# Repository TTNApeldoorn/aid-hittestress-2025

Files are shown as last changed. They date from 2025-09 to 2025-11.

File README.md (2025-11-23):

# aid-hittestress-2025

These climate sensors are designed for the LIFE-IP Climate adaption project in Apeldoorn. The sensors measures temperature, humidity and air quality.
The sensors are mounted in lampposts and communicate via LoRAWan with the TTN network.

## Requirements 
- The sensor measures each 2.5 minutes temperatue, humidity and particular matter PM1.0, 2.5 and 10
- The sensor sends the measurements to the TTN network using LoRaWan radio
- The sensor can be mounted on lamppost (case IP65)
- The sensor operates on LiPo battery (for minimal 18 hours) and can be charged by 230V supply 
- The sensor battery is charged at night by the lamppost
- GPS location and battery voltage are reported at regular intervals

## Realization

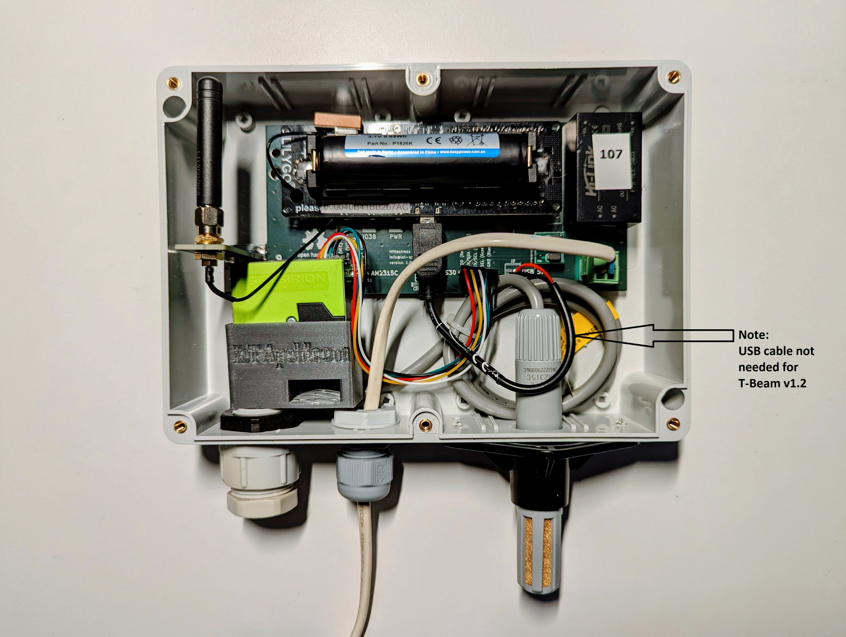
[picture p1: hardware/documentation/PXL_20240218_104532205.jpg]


 Climate Sensor in Kradex housing

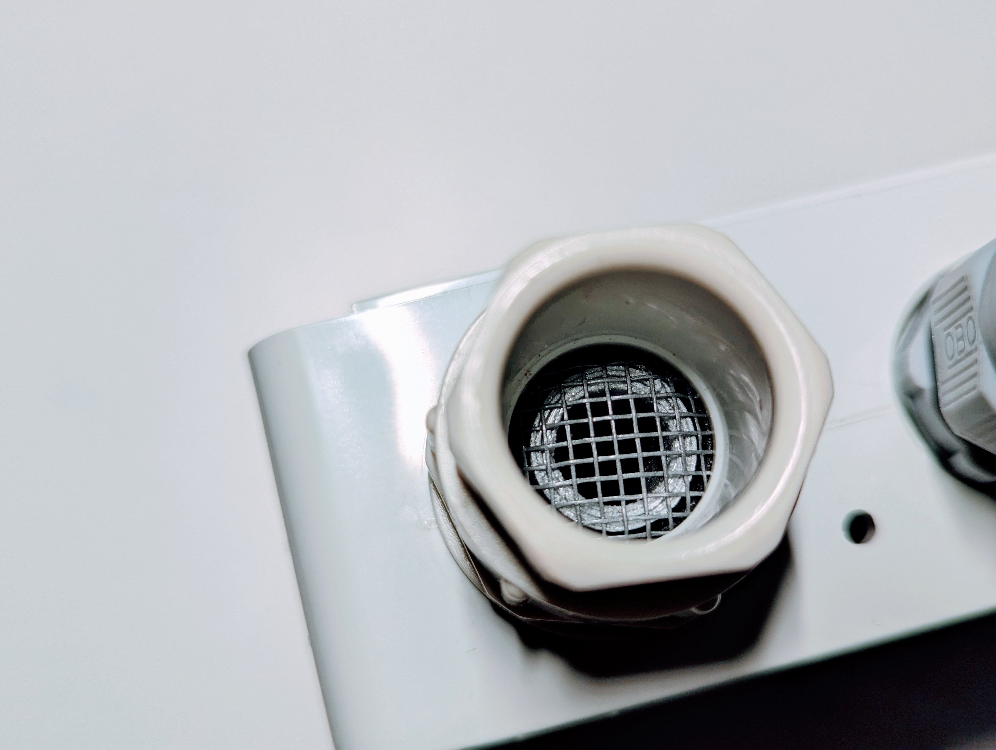
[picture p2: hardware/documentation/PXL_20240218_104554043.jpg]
 

Air inlet particle sensor, with insect sreen

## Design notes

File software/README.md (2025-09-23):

# LIFE-IP Climate sensor 2025
These climate sensors are designed for the LIFE-IP climate adaption project in Apeldoorn.

## Hardware:
- LilyGO TTGO T-Beam V1.2 - LoRa 868MHz - NEO-M8N GPS - ESP32 
- Sensirion SPS30 Particulate matter sensor i2c
- AM2315C Temperature/humidity sensor i2c
- 18650 Li-ion Batterij - 2600mAh
- Hi-Link PCB Supply - 5VDC 1A
- Mini DC-DC 5V Step-up Boost Converter 480mA
- PCB for connecting components
- Kradex housing 176x126x57mm - IP65

Note that there exist several different types of LilyGo T-Beam versions with different power managent modules and LoRa modules. This documentation describes the **LilyGO T-Beam V1.2** with:
- AXP2101 power module
- SX1276 LoRa module
- NEO-M8N GNSS GPS module

More info see https://github.com/Xinyuan-LilyGO/LilyGo-LoRa-Series
## Software 

### Prerequisites:
- Visual Studio with Platform IO
- LMIC-Arduino LoRa library
- mikalhart/TinyGPSPlus GPS library
- sensirion/sensirion-sps particicle matter SPS30 library
- lewisxhe/XPowersLib power control AXP2101
- RobTillaart/AM2315C library for the i2c AM2315C sensor
- espressif32@6.9.0 platform with board lilygo t-beam

The **platformio.ini** takes care for the required settings end libraries. LMIC library is already included in the project sources.

## Instructions
### LoRaWan TTN keys
The file **utilities.h** defines the TTN keys APPEUI and APPKEY.
The unique DEVEUI key is obtained from the T-BEAM board id.

## TTN interface
Two type of messages are sent by the sensor:
- measurement report (each 2.5 minutes), send on TTN port 15
- status report (eachtime after 100 measurement reports), send on TTN port 16

Measurement report contains:
- temperature in C
- Relative Humidity in %
- Particulate Matter 1.0 μg/m3
- Particulate Matter 2.5 μg/m3
- Particulate Matter 10 μg/m3
- Battery voltage in V

Status report contains:
- GPS position lat/lon, hdop, altitude
- Sensor version
- batterij voltage

The binary messages from the Sensor are converted by the TTN Payloaddecoder into Json.  
Example JSON measurement message:

> {"pm10":8.5,"pm1p0":7.22,"pm2p5":8.02,"rh":99.99,"temp":7.82,"vbat":4.037}

Example JSON status message:
> {"latitude":52.224578,"longitude":6.0061902,"alt":0.0,"hdop":1.61,vbat":4.099,"SwVer":3.02 }

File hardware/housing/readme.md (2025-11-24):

# Drillplan

This is the [drillplan](drillPlan.png) for the housing. 
The drill plan shows the bottom plane of a [Kradex Z74 ABS enclosure](../documentation/Z74.pdf).

## Overview of the housing

Overview interals of housing

>This is the previous version using the older version of the Heltec T-Beam that is powered over USB.

SDS030 particle sensor raster inlet

>This shows the raster of the SPS30 particle sensor.

## SPS30 holder

The [SPS30 holder](hittestress2025_SPS_omhulsel_TPU.stl) is a devative work from [pe0ter](https://www.thingiverse.com/pe0ter) his [SPS30 PM sensor adapter](https://www.thingiverse.com/thing:4851976).

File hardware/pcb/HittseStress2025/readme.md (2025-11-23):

# HittseStress2025 PCB Design

This directory contains the KiCad project files for the HittseStress2025 printed circuit board (PCB). This PCB is designed to interface the TTGO T-Beam ESP32 LoRa module with the SPS30 particulate matter sensor and other components for the climate sensor system.

## Contents

- `HittseStress2025.kicad_pcb` - PCB layout file
- `HittseStress2025.kicad_sch` - Schematic file
- `HittseStress2025.kicad_pro` - KiCad project file
- `gerbers/` - Gerber files for PCB manufacturing
- `my-KiCad-library/` - Custom KiCad symbols and footprints
- `HittseStress2025-backups/` - Automatic backup files

## Purpose

The PCB serves as a shield/breakout board that provides:
- Power management connections
- Interface connections for the SPS30 particulate matter sensor
- Proper pin routing for the ESP32-based TTGO T-Beam module
- Support for battery charging and power supply from the lamppost

This board enables the climate sensor to be mounted in lampposts and operate on battery power with charging capability.

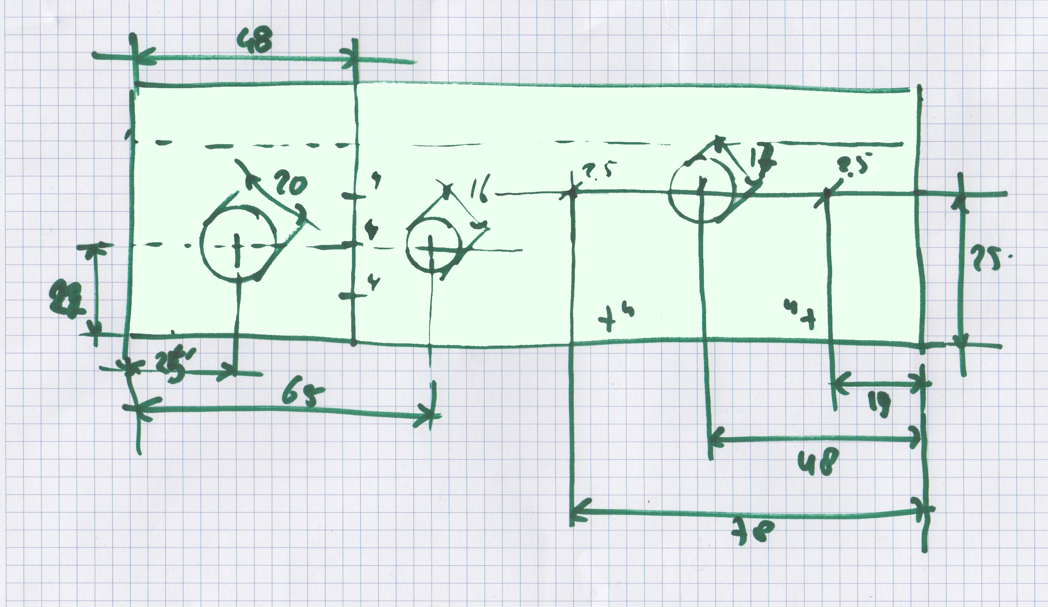
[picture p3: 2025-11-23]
hardware/housing/drillPlan.jpg

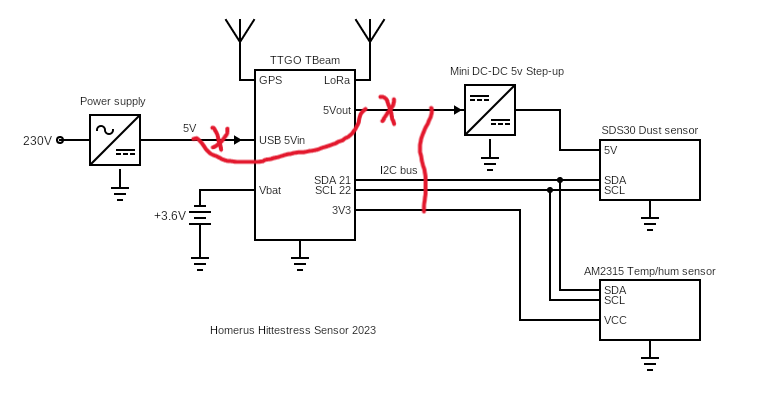
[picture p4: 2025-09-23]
hardware/pcb/workbench/wijziging-schema.png

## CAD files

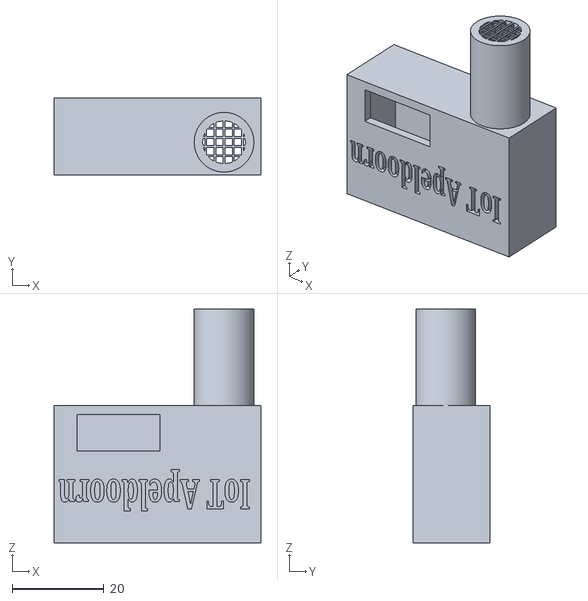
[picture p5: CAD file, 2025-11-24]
hardware/housing/hittestress2025_SPS_omhulsel_TPU.stl
45.0 x 16.7 x 51.0

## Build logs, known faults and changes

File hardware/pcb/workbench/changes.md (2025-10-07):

Er zijn helaas toch nog wat PCB wijzigingen.
De 5V pin van de LilyGO T-Beam V1.2 is nu zowel input als output en is gekoppeld met de USB 5V. Dus de micro-USB stekker kan hiermee vervallen.
Deze 5V pin geeft geen output meer als de sensor op batterij draait, dat was bij de oude versie wel zo.
Dus nu moet de input pin van de step-up (nodig voor de SDS10) aan de 3V3 van de T-Beam aangesloten worden i.p.v. de 5V output.
Ik heb dit aangepast met 2 draadjes en een spoortje doorkrassen, zie foto.

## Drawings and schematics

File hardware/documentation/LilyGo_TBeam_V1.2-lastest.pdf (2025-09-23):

D

5 | 4 | 3 | 2 | 1

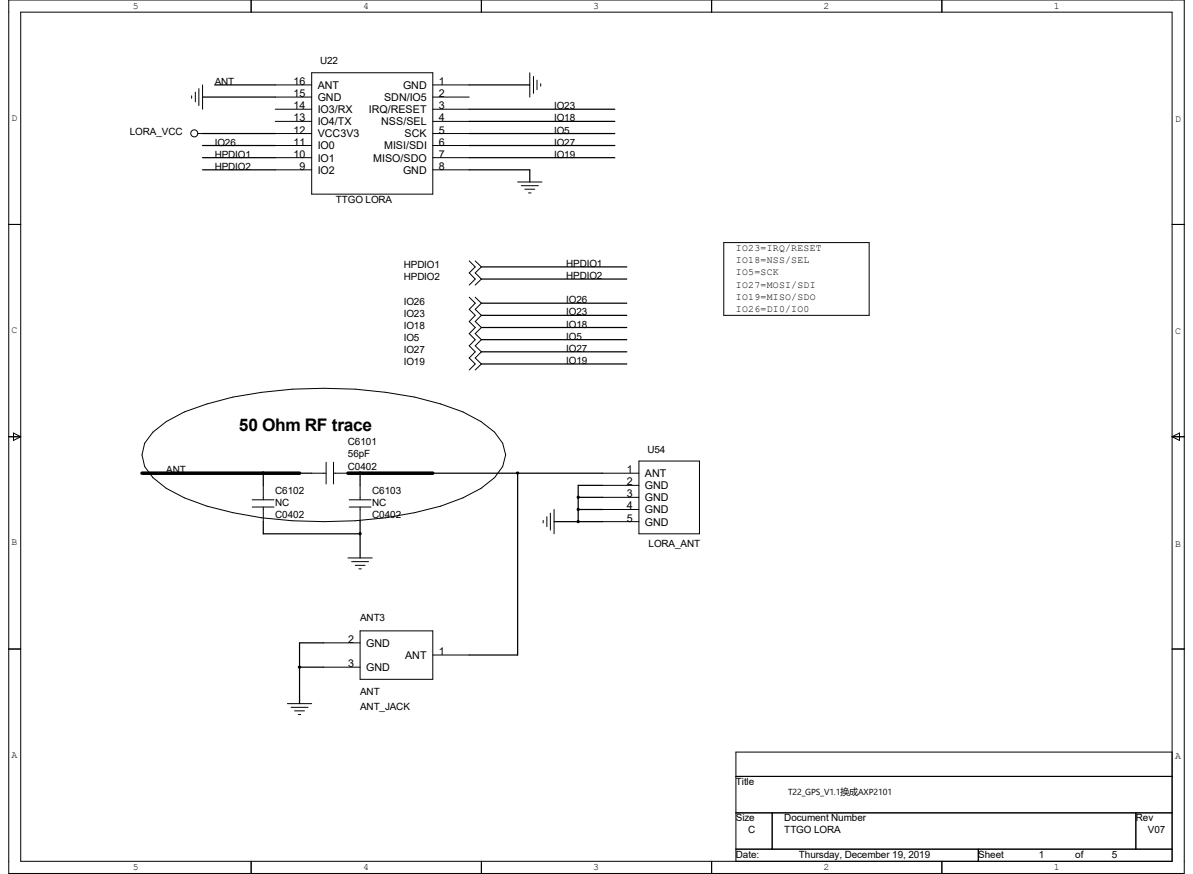
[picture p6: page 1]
T22_GPS_V1.1换成AXP2101; Title; IO23=IRQ/RESET IO18=NSS/SEL IO5=SCK IO27=MOSI/SDI IO19=MISO/SDO IO26=DI0/IO0; 1 ANT 2 GND 3 GND 4 GND 5 GND; LORA_ANT; 1 ANT; 2 GND; 3 GND; ANT3; ANT_JACK; ANT; 16 ANT; MISO/SDO; MISI/SDI; 5 SCK; 4 NSS/SEL; 12 VCC3V3; GND; 3 IRQ/RESET; 2 SDN/IO5; 15 GND; TTGO LORA; LORA_VCC; HPDIO1 HPDIO2; HPDIO2; HPDIO1

50 Ohm RF trace

Size C | Document Number TTGO LORA | Rev V07

Date: Thursday, December 19, 2019 | Sheet 1 of 5

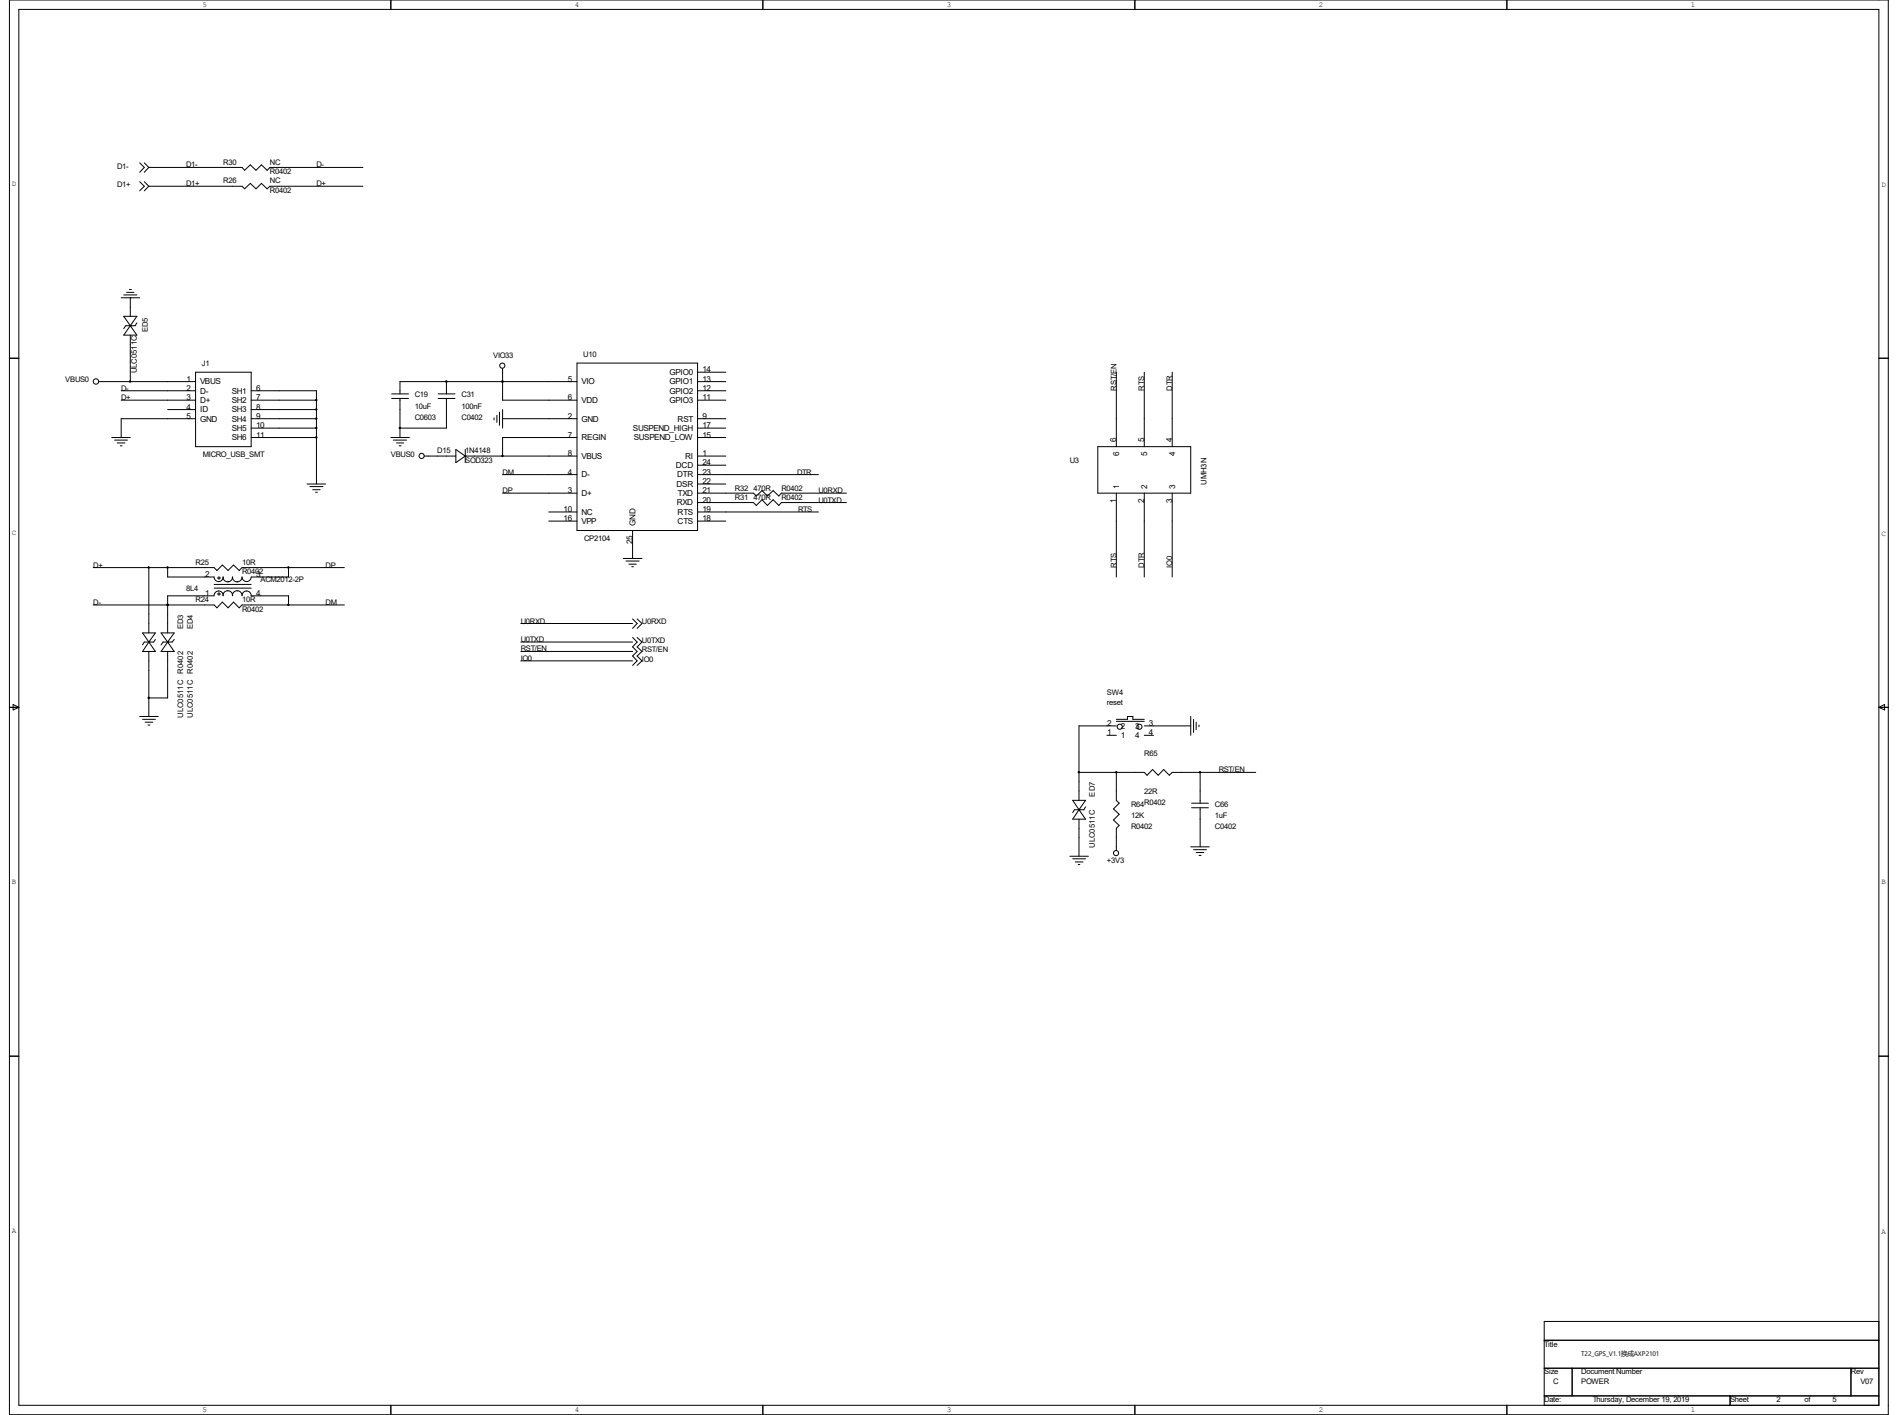
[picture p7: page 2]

RST/EN

D
D

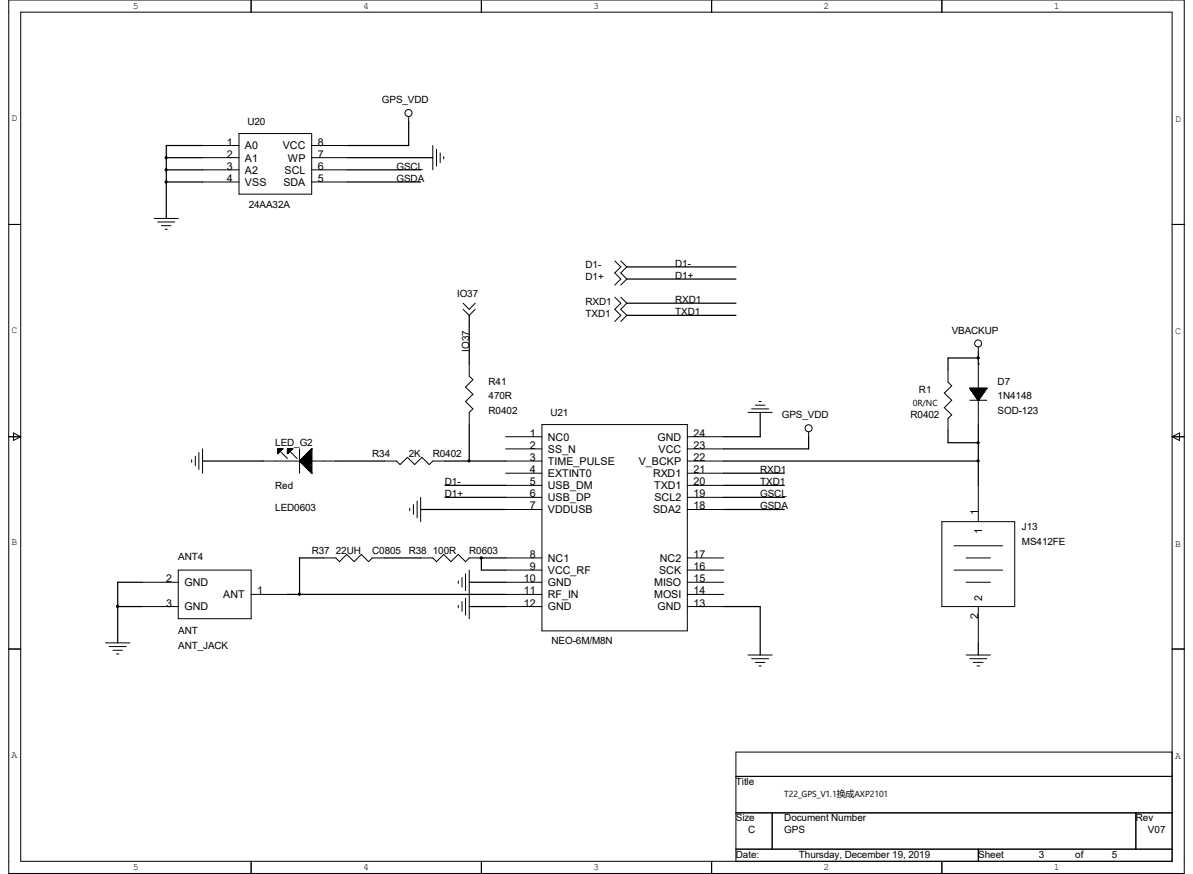
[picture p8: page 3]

C | GPS | V07

Date: | Sheet 3 of 5

# ESP32 Module:with 1.8V Flash & SRAM

The operating voltage for signals marked in blue is 1.8V.

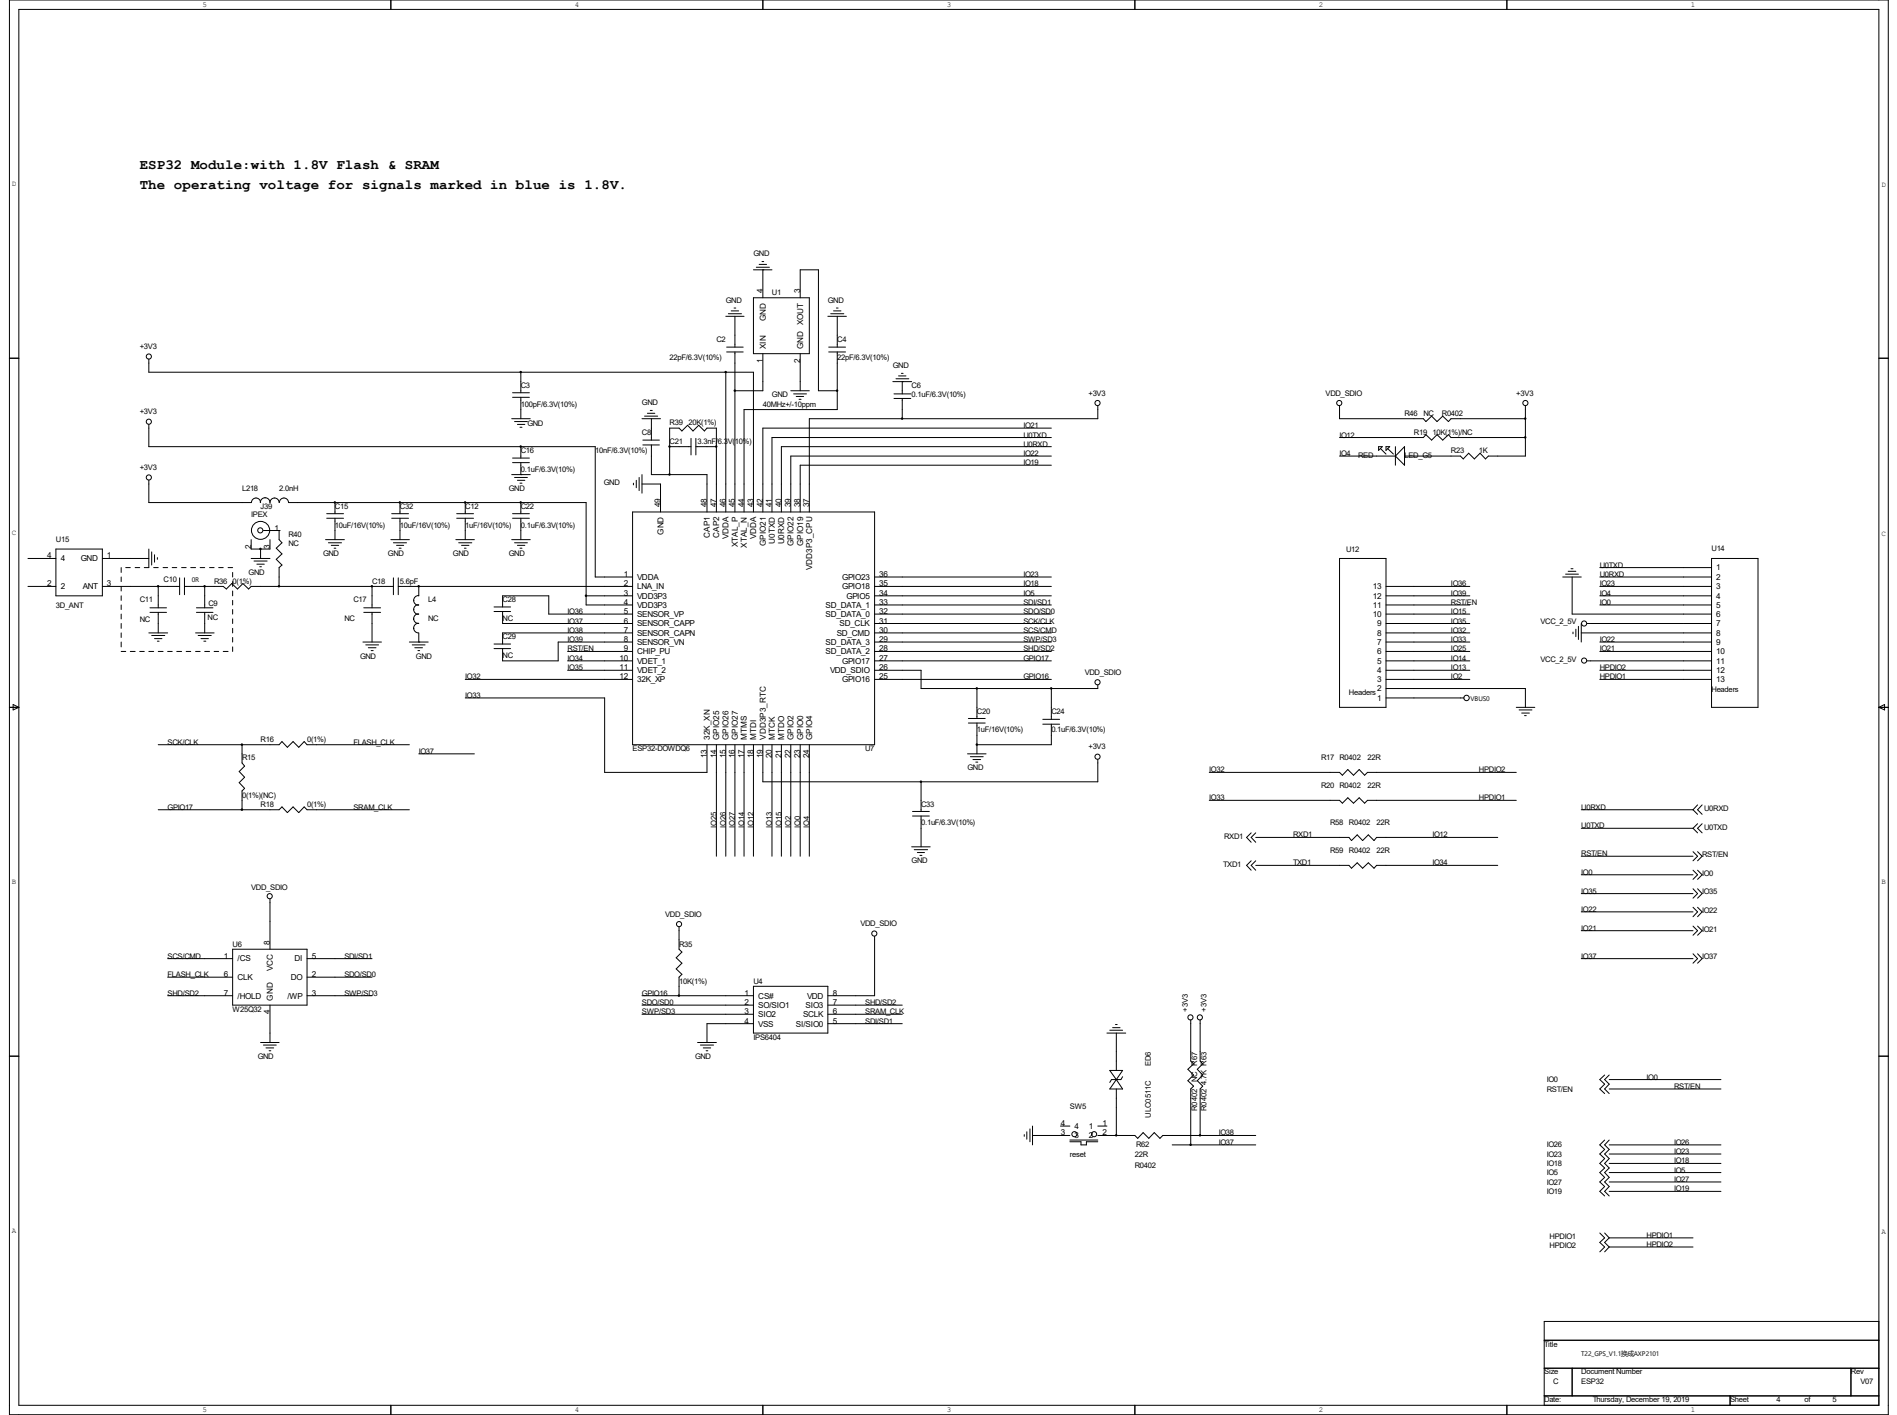
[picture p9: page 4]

## above 30 miles

## above 50 miles

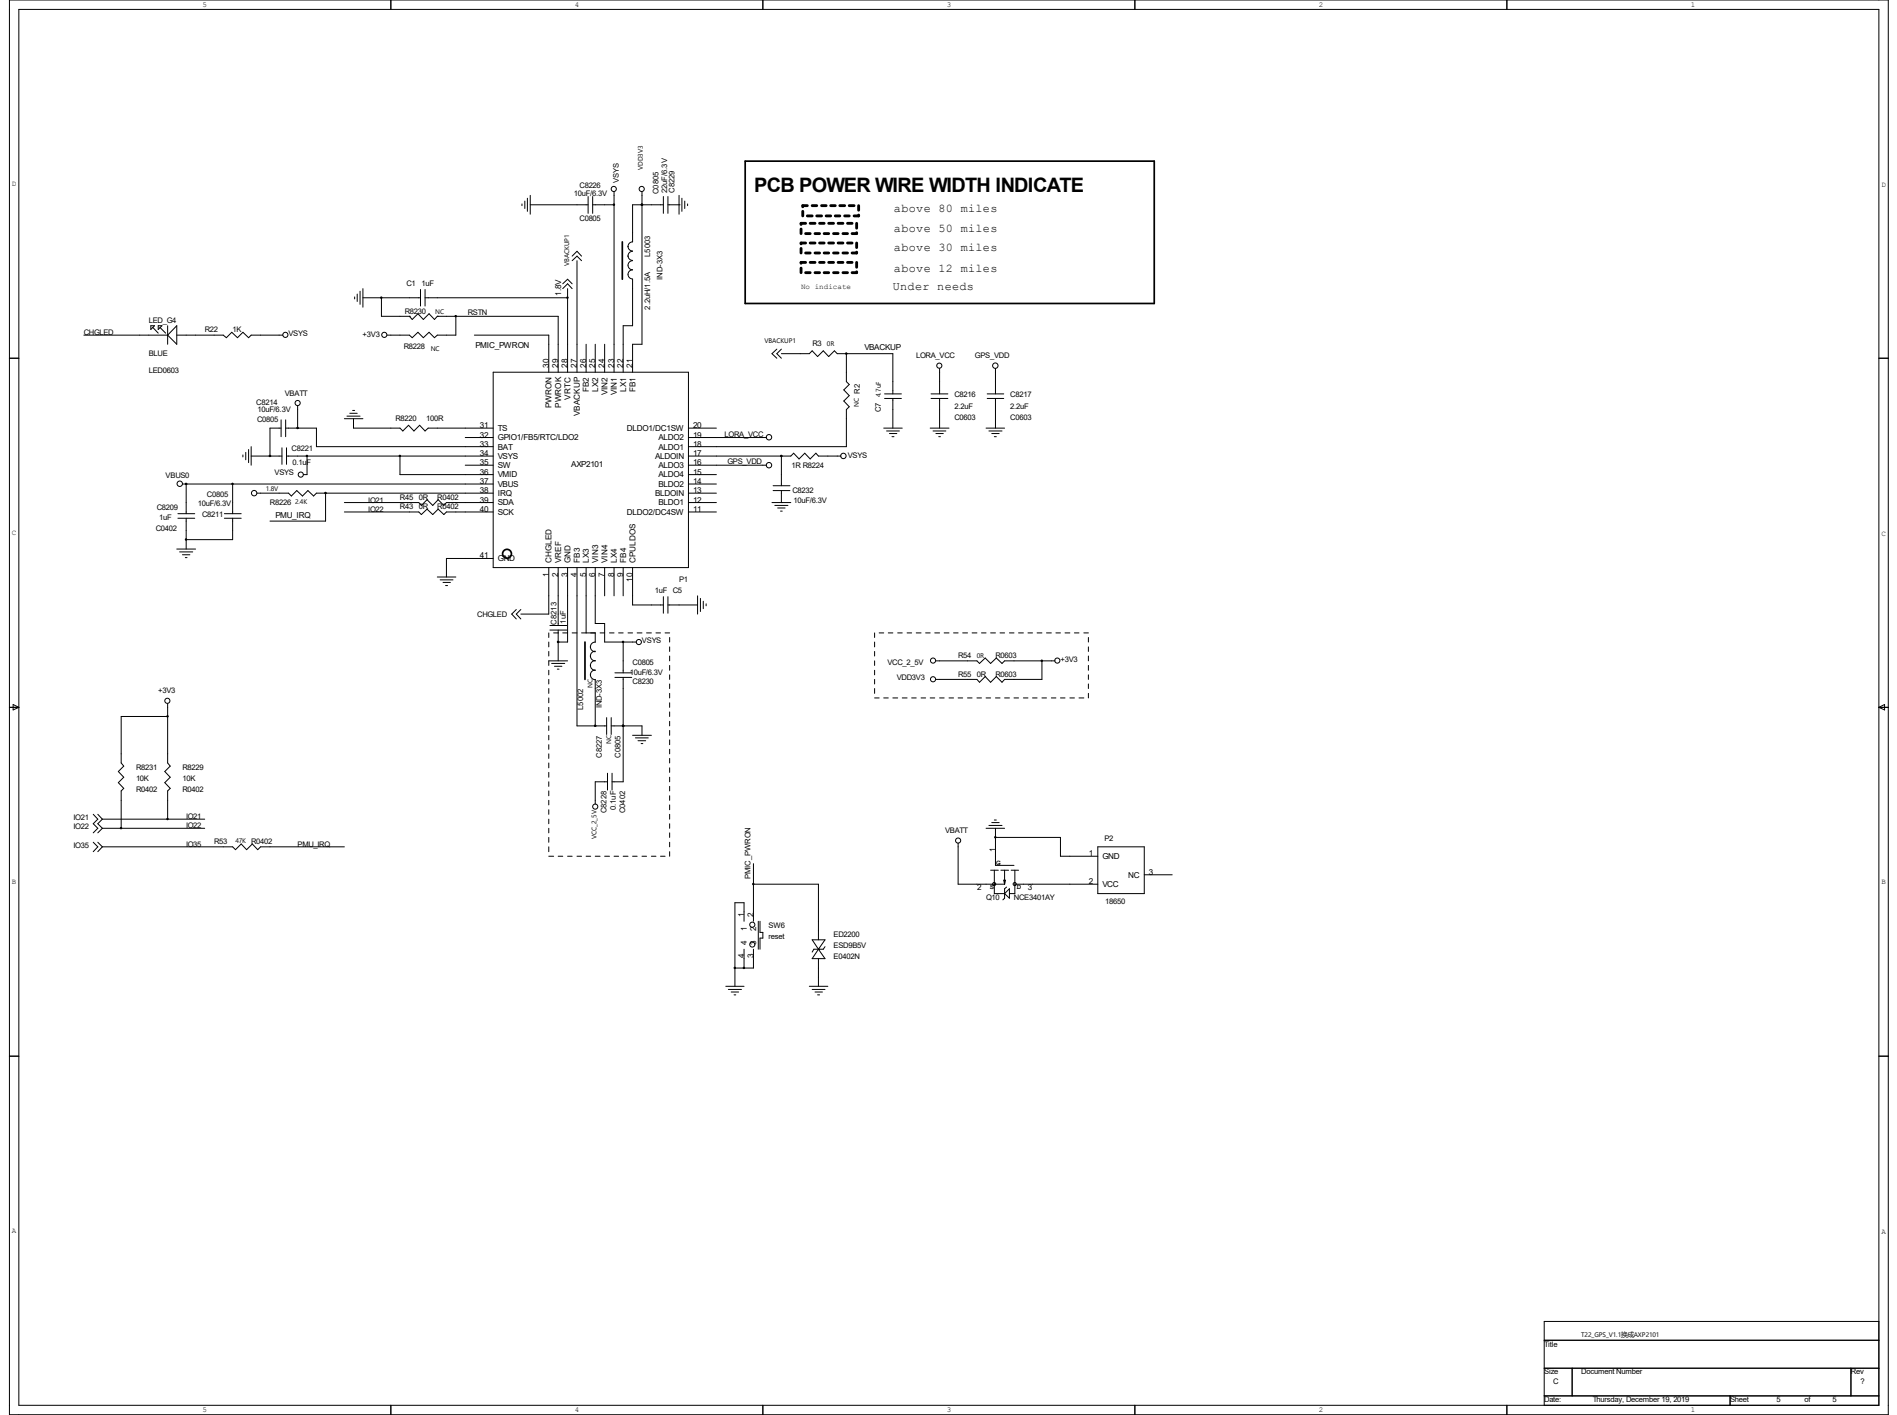
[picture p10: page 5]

PCB POWER WIRE WIDTH INDICATE

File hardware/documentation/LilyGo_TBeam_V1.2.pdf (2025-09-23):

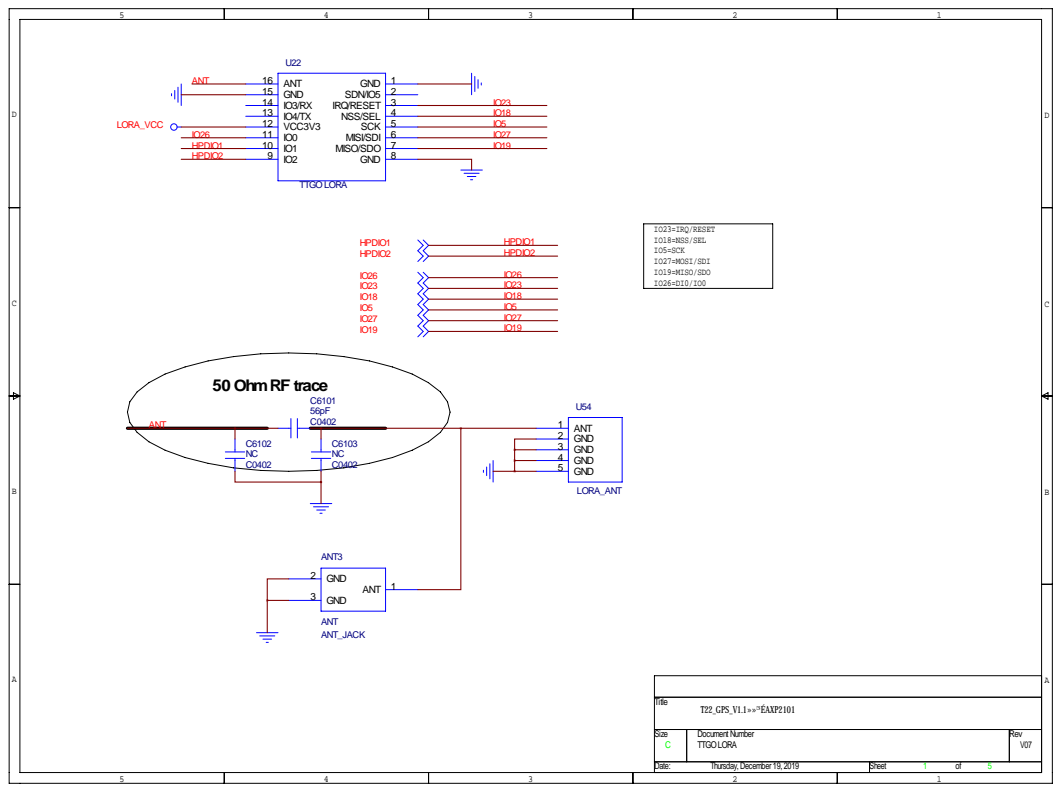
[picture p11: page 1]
T22_GPS_V1.1»»³ÉAXP2101; Title; IO23=IRQ/RESET; IO18=NSS/SEL; IO5=SCK; IO27=MOSI/SDI; IO19=MISO/SDO; ANT; GND; LORA_ANT; 1 ANT; ANT3; ANT_JACK; MISO/SDO; MISI/SDI; 5 SCK; 4 NSS/SEL; VCC3V3; 3 IRQ/RESET; 2 SDN/IO5; TTGO LORA; LORA_VCC; HPDIO1 HPDIO2; HPDIO2; HPDIO1

50 Ohm RF trace

Size C | Document Number TTGO LORA | Rev V07

Date: Thursday, December 19, 2019 | Sheet 1 of 5

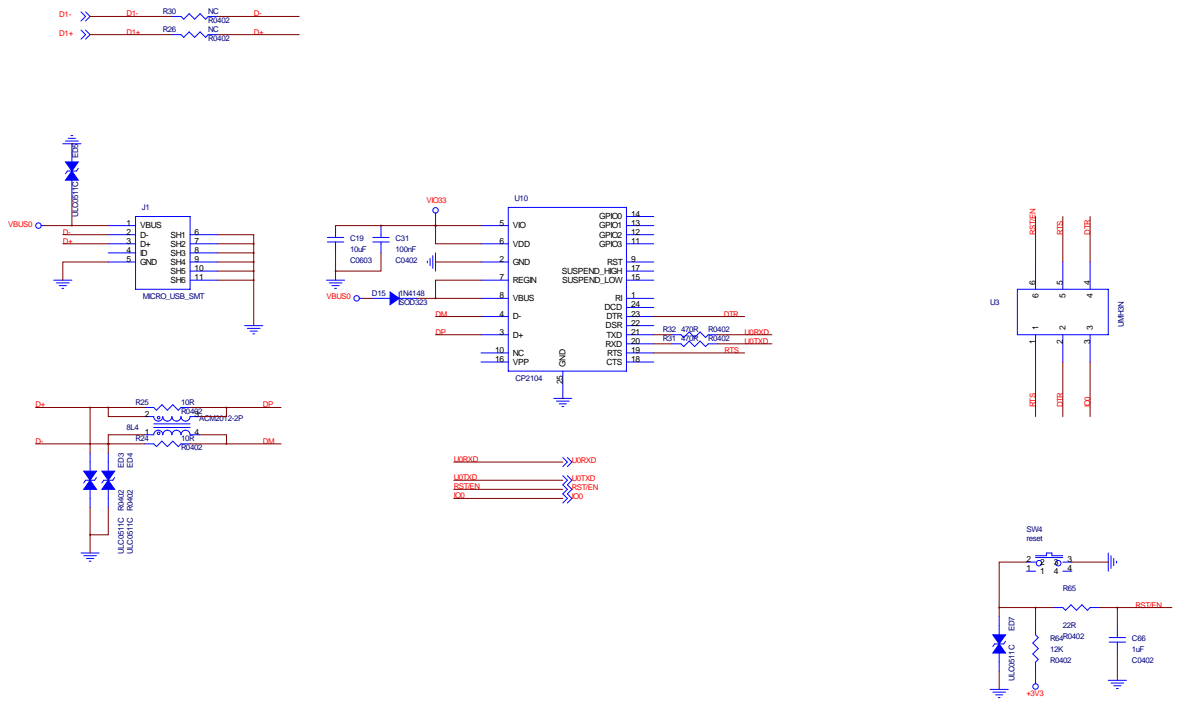
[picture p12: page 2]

C | POWER | V07

Date: Thursday, December 19, 2019 | Sheet 2 of 5

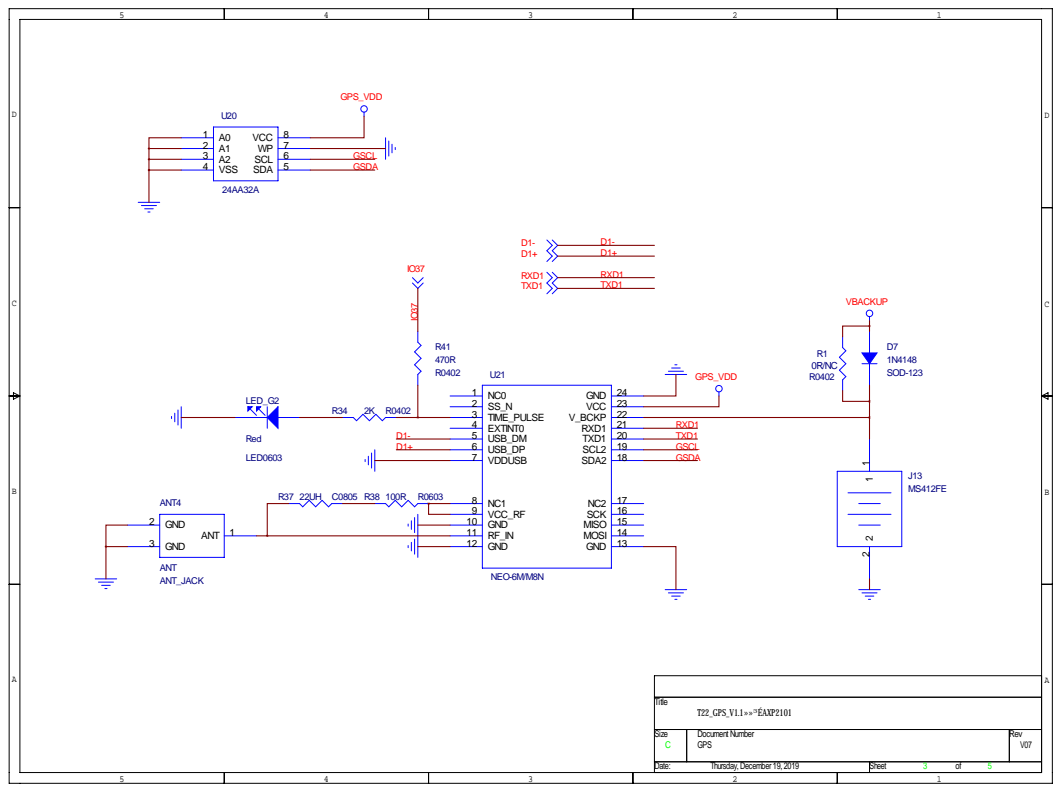
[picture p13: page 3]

C | GPS | V07

Date: | Sheet 3 of 5

## ESP32 Module:with 1.8V Flash & SRAM

The operating voltage for signals marked in blue is 1.8V.

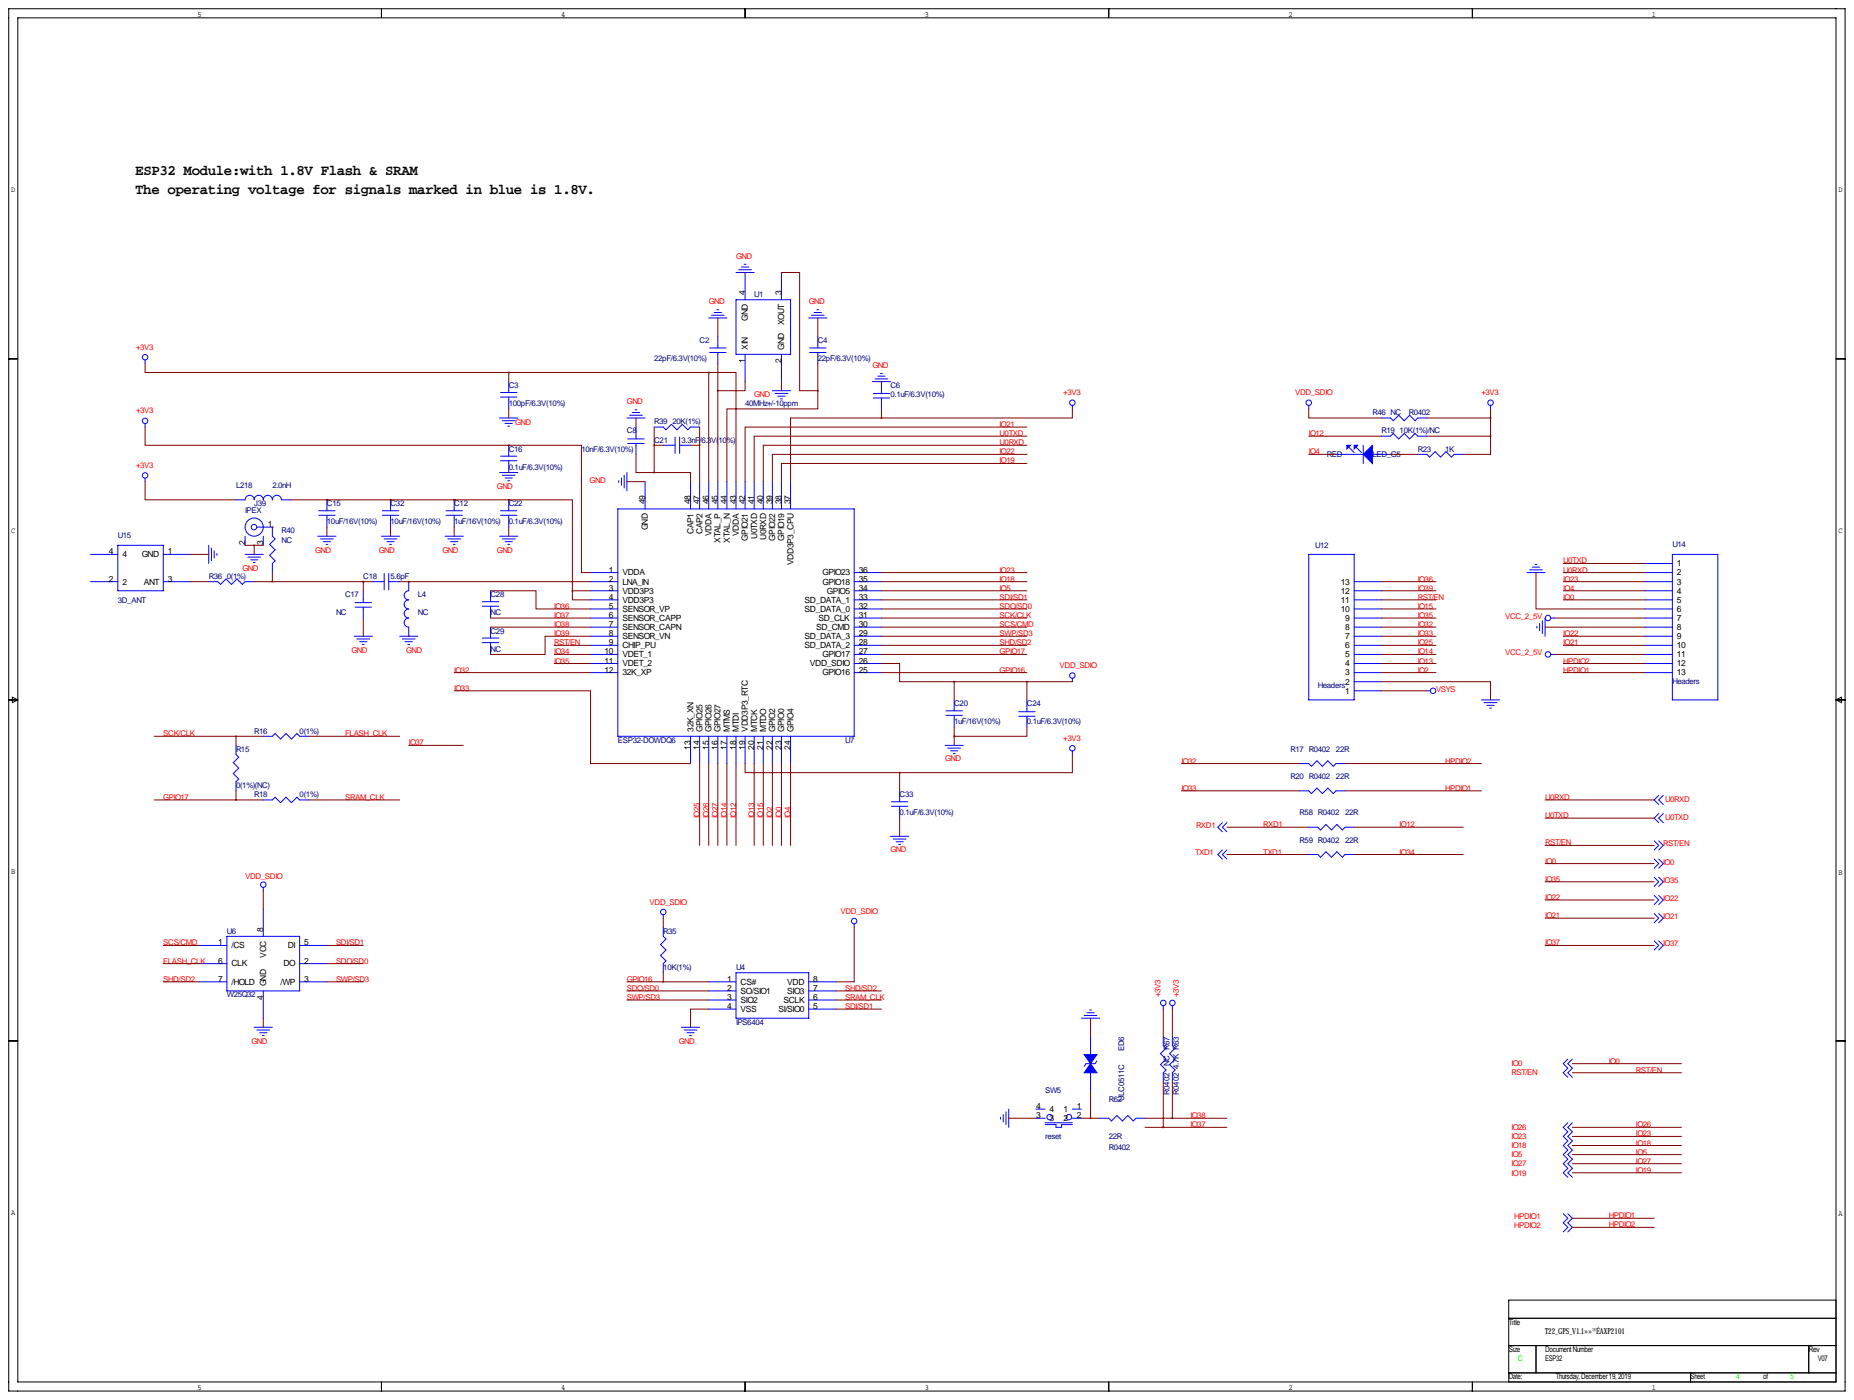
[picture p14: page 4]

C | ESP32 | V07

Date: | Sheet 4 of 5

# PCB POWER WIRE WIDTH INDICATE

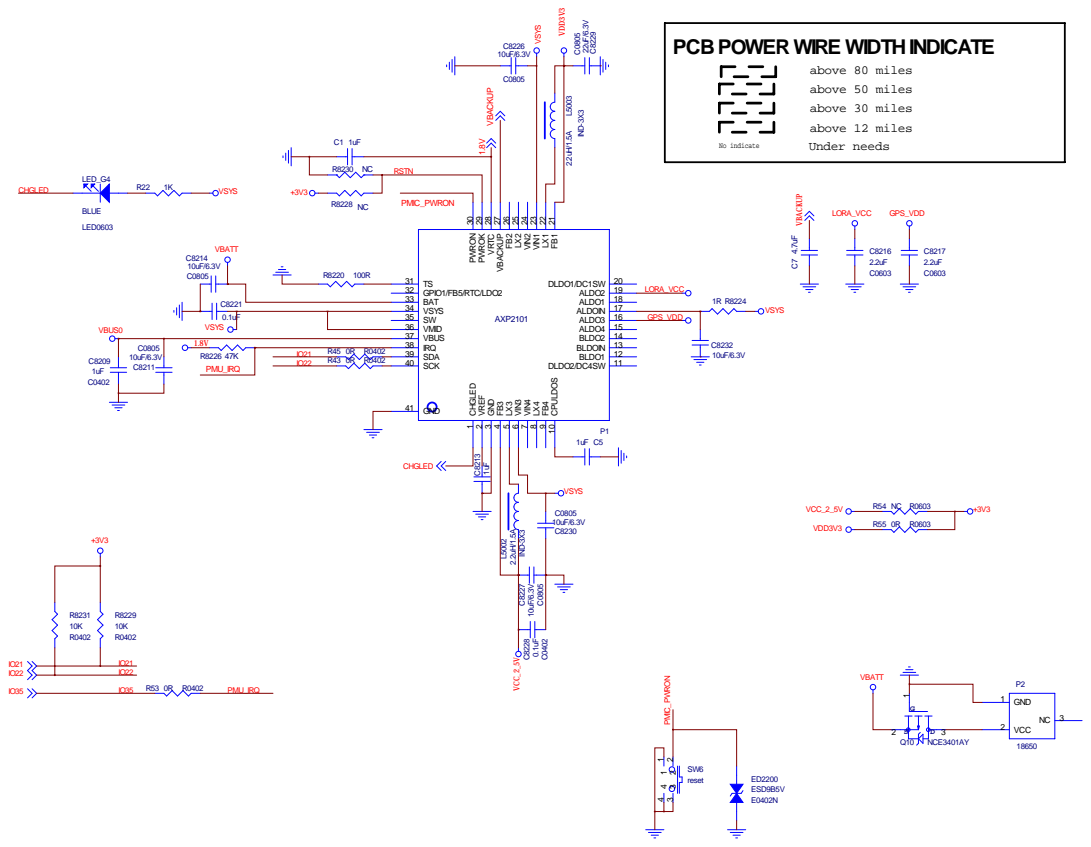
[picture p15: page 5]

Date: Thursday, December 19, 2019 | Sheet 5 of 5

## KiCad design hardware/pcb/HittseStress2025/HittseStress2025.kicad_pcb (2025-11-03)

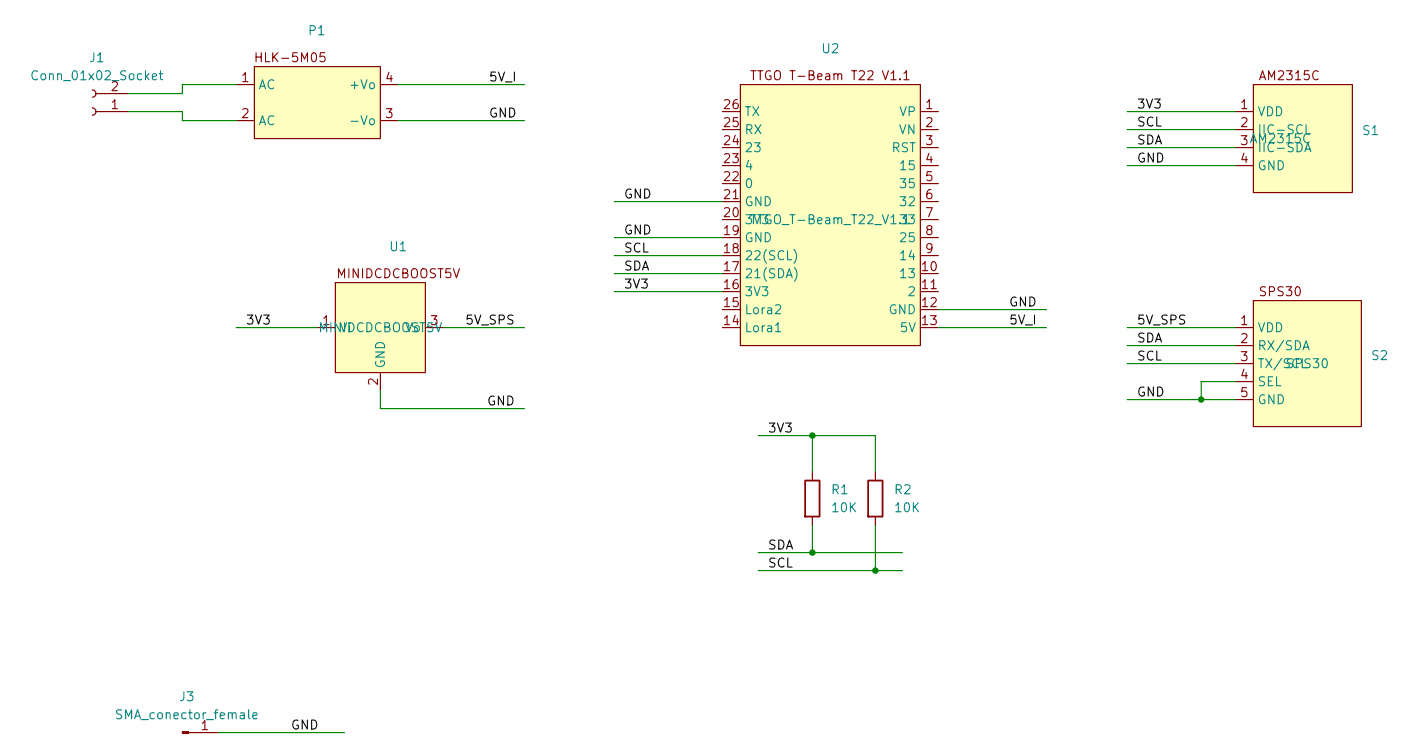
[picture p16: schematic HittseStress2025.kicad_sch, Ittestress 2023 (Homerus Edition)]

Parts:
J1: Conn_01x02_Socket; PhoenixContact_MCV_1,5_2-G-5.08_1x02_P5.08mm_Vertical
J3: SMA_conector_female; SMA-ANT-CONN
P1: HLK-5M05
R1, R2: 10K; R_Axial_DIN0309_L9.0mm_D3.2mm_P12.70mm_Horizontal
S1: AM2315C
S2: SPS30
U1: MINIDCDCBOOST5V
U2: TTGO_T-Beam_T22_V1.1

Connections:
/3V3: R1.1, R2.1, S1.1 (VDD), U1.1 (Vi), U2.16 (3V3)
/5V_I: P1.4 (+Vo), U2.13 (5V)
/5V_SPS: S2.1 (VDD), U1.3 (Vo)
/GND: J3.1, P1.3 (-Vo), S1.4 (GND), S2.4 (SEL), S2.5 (GND), U1.2 (GND), U2.12 (GND), U2.19 (GND), U2.21 (GND)
/SCL: R2.2, S1.2 (IIC-SCL), S2.3 (TX/SCL), U2.18 (22(SCL))
/SDA: R1.2, S1.3 (IIC-SDA), S2.2 (RX/SDA), U2.17 (21(SDA))
unnamed: J1.1, P1.2 (AC)
unnamed: J1.2, P1.1 (AC)

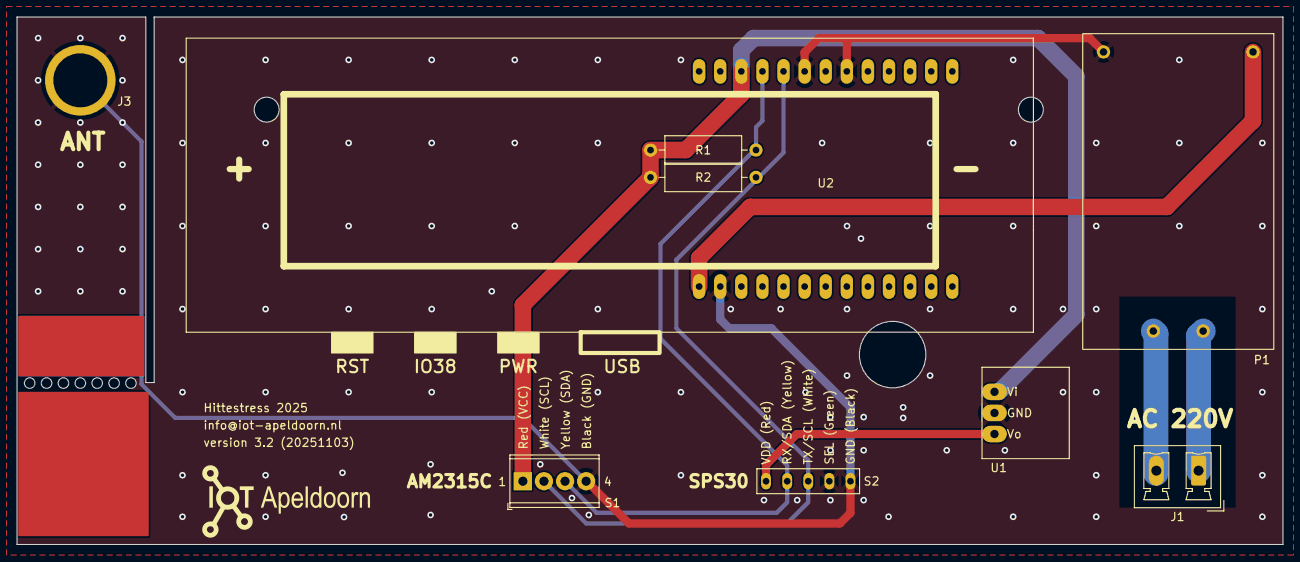
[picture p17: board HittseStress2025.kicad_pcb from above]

Board: 2 copper layers, 152.4 x 63.5 mm, 9 parts (0 on the bottom side), 8 nets.

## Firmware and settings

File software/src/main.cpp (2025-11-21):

/*

  Main module

  # Modified by Kyle T. Gabriel to fix issue with incorrect GPS data for TTNMapper

  Copyright (C) 2018 by Xose Pérez <xose dot perez at gmail dot com>

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
  You should have received a copy of the GNU General Public License
  along with this program.  If not, see <http://www.gnu.org/licenses/>.
*/

#include "utilities.h"
#include "pmu.h"
#include "rom/rtc.h"
#include "AM2315C.h"
#include "ttn.h"
#include "gps.h"
#include "mysps30.h"

// deep sleep support
RTC_DATA_ATTR int bootCount = 0;

// LoRa payload structs
struct Msg {
  int16_t temp, hum, pm2_5, pm10, batt, pm1_0;
};
static Msg msg = {0, 0, 0, 0, 0, 0}; 

struct Stat {
  float lat, lng;
  int16_t alt, hdop, batt, version, cputemp;
};
static Stat stat = {0.0, 0.0, 0, 0, 0, 0, 0}; 

// Sensors
Gps gps;          // GPS sensor
AM2315C am2315;  // temperature hum sensor
Sps30 sps30;     // dust sensor

bool packetSent = false, packetQueued = false;
bool sensorCycle = false, gpsCycle = false;
int start;

// -----------------------------------------------------------------------------
// Application
// -----------------------------------------------------------------------------

void sleep(int msec) {
  printf("sleep for %d\n", msec);
  ttn_shutdown();
  Serial.flush();
  PMUSavingMode();  // turn off LORA and GPS power
  delay(500);

/*
  // FIXME - use an external 10k pulldown so we can leave the RTC peripherals powered off
  // until then we need the following lines
  esp_sleep_pd_config(ESP_PD_DOMAIN_RTC_PERIPH, ESP_PD_OPTION_ON);

  // Only GPIOs which are have RTC functionality can be used in this bit map: 0,2,4,12-15,25-27,32-39.
  uint64_t gpioMask = (1ULL << BUTTON_PIN);

  // FIXME change polarity so we can wake on ANY_HIGH instead - that would allow us to use all three buttons (instead of just the first)
  gpio_pullup_en((gpio_num_t)BUTTON_PIN);
  esp_sleep_enable_ext1_wakeup(gpioMask, ESP_EXT1_WAKEUP_ALL_LOW);
*/

  esp_sleep_enable_timer_wakeup( msec * 1000ULL);  // call expects usecs
  esp_deep_sleep_start();
}

void _txCallback() {
  // We only want to say 'packetSent' for our packets (not packets needed for joining)
  printf("_txCallback\n");
  if (packetQueued) {
    printf("Message sent\n");
    packetQueued = false;
    packetSent = true;
  }
}

void _rxCallback(unsigned int port, uint8_t* buf, unsigned int len) {
  printf("[TTN] Response: ");
  for (int i = 0; i < len; i++) {
    printf("%02x ", buf[i]);
  }
  printf("\n");
}

void acquireSensorData()
{
  printf("sensor cycle\n");
  // read dust
  if (!sps30.init())  {
    sleep(60000); // Error, do deepsleep retry afer one minute
  }
  if( bootCount == 1 )
    sps30.startManaualFanCleaning();

  if (sps30.read())  {
    msg.pm1_0 = sps30.pm1_0 * 100;
    msg.pm2_5 = sps30.pm2_5 * 100;
    msg.pm10 = sps30.pm10 * 100;
    printf("pm1=%d pm2.5=%d pm10=%d\n", msg.pm1_0, msg.pm2_5, msg.pm10);
  }
  // read temperature and humidity
  if (!am2315.begin())  {
    printf("am2315 module not found!\n");
    sleep(60000); // Error, do deepsleep retry afer one minute
  }
  if (am2315.read() == AM2315C_OK)  {
    msg.temp = am2315.getTemperature() * 100;
    msg.hum = am2315.getHumidity() * 100;
    msg.batt = PMU->getBattVoltage();
    printf("temp=%d  hum=%d\n", msg.temp, msg.hum);
  }
}

void acquireStatusData()
{
  printf("gps cycle\n");
  PMU->enablePowerOutput(XPOWERS_ALDO3);  // set GPS POWER on !!!
  delay(500);  // wait a moment, he power is back on.
  if (!gps.init() )
     sleep(60000); // Error, do deepsleep retry afer one minute
   
  if( gps.read())  {
    stat.lat = gps.lat;
    stat.lng = gps.lng;
    stat.hdop = gps.hdop;
    stat.alt = gps.alt;
  }
  stat.version = APP_VERSION * 100;
  stat.batt = PMU->getBattVoltage();
  stat.cputemp = temperatureRead() * 100;
}

void setup() {
  Serial.begin(115200);

  if( !PMUsetup() ) {
    printf( "PMU error\n");
    sleep( 60000);  // Error, do deep sleep retry afer one minute
  }

  if( bootCount >= 1000)   // force a new join after n cycles (ca 30 hours)
    bootCount = 1;
  else
    bootCount++;

  printf( "bootCount = %d\n", bootCount);
  if (bootCount == 1)
    ttn_erase_prefs();

  // TTN setup
  if (!ttn_setup()) {
    printf("Radio module not found!\n");
    sleep( 60000);  //  Error, do deepsleep retry afer one minute
  }

// LoRa Tx Rx callbacks
  ttn_register_rxReady(_rxCallback);
  ttn_register_txReady(_txCallback);

// after 30 sensor cycles, a statuscycle is processed (ca every hour)
  if (bootCount % 30) {      
    sensorCycle = true;
    acquireSensorData();
  }
  // send status and gps position
  else {
    gpsCycle = true;
    acquireStatusData();
  }
  start = millis();
  printf("setup end\r\n");
}

// the loop function processes the send to TTN message 
void loop() {

  ttn_loop();
  
  if( ttn_connected() && !packetQueued && !packetSent) {
    if( sensorCycle )
      ttn_send((uint8_t*)&msg, sizeof(msg), 15);
    else
      ttn_send((uint8_t*)&stat, sizeof(stat), 16);
    packetQueued = true;
  }

  // if packet has been sent, or asume the packet has been sent after 10 sec, 
  // start the deepsleep
  if( packetSent  || millis() - start > 10000) {
    packetSent = false;
    
    if( gpsCycle )
       sleep( 10000);          // do a short sleep, a gps cycle is an in between cycle
    else
      sleep( SEND_INTERVAL);  
  }
}

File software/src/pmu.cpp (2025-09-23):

/**
 * @file      boards.cpp
 * @author    Lewis He (lewishe@outlook.com)
 * @license   MIT
 * @copyright Copyright (c) 2024  ShenZhen XinYuan Electronic Technology Co., Ltd
 * @date      2024-04-24
 * @last-update 2025-05-26
 *
 */

#include "utilities.h"
#include "pmu.h"
#include "soc/rtc.h"
#include "driver/gpio.h"


//static DevInfo_t  devInfo;
//uint32_t deviceOnline = 0x00;

XPowersLibInterface *PMU = NULL;
bool     pmuInterrupt;
static void setPmuFlag() {
    pmuInterrupt = true;
}

static void printWakeupReason();
static void printPMUVoltages();

bool PMUsetup()
{
    Serial.println("setupBoards");
    printWakeupReason();
    /*
    * T-Beam LED defaults to low level as turn on,
    * so it needs to be forced to pull up
    * * * * */
    gpio_hold_dis((gpio_num_t)BOARD_LED);
    pinMode(BOARD_LED, OUTPUT);
    digitalWrite(BOARD_LED, LED_ON);
    pinMode(RADIO_DIO2_PIN, INPUT);

    if (!PMU) {
        PMU = new XPowersAXP2101(Wire);
        if (!PMU->init()) {
            Serial.println("Warning: Failed to find AXP2101 power management");
            delete PMU;
            PMU = NULL;
        } else {
            Serial.println("AXP2101 PMU init succeeded, using AXP2101 PMU");
        }
    }
    else
      return false;

   // PMU->setChargingLedMode(XPOWERS_CHG_LED_CTRL_CHG);

    pinMode(PMU_IRQ, INPUT_PULLUP);
    attachInterrupt(PMU_IRQ, setPmuFlag, FALLING);
    if (PMU->getChipModel() == XPOWERS_AXP2101) {
        //Unuse power channel
        PMU->disablePowerOutput(XPOWERS_DCDC2);
        PMU->disablePowerOutput(XPOWERS_DCDC3);
        PMU->disablePowerOutput(XPOWERS_DCDC4);
        PMU->disablePowerOutput(XPOWERS_DCDC5);
        PMU->disablePowerOutput(XPOWERS_ALDO1);
        PMU->disablePowerOutput(XPOWERS_ALDO4);
        PMU->disablePowerOutput(XPOWERS_BLDO1);
        PMU->disablePowerOutput(XPOWERS_BLDO2);
        PMU->disablePowerOutput(XPOWERS_DLDO1);
        PMU->disablePowerOutput(XPOWERS_DLDO2);
        PMU->disablePowerOutput(XPOWERS_CPULDO);

        // GNSS RTC PowerVDD 3300mV
        PMU->setPowerChannelVoltage(XPOWERS_VBACKUP, 3300);
        PMU->enablePowerOutput(XPOWERS_VBACKUP);

        //ESP32 VDD 3300mV
        // ! No need to set, automatically open , Don't close it
        // PMU->setPowerChannelVoltage(XPOWERS_DCDC1, 3300);
        // PMU->setProtectedChannel(XPOWERS_DCDC1);
        PMU->setProtectedChannel(XPOWERS_DCDC1);

        // LoRa VDD 3300mV
        PMU->setPowerChannelVoltage(XPOWERS_ALDO2, 3300);
        PMU->enablePowerOutput(XPOWERS_ALDO2);

        //GNSS VDD 3300mV 
        PMU->setPowerChannelVoltage(XPOWERS_ALDO3, 3300);
        //PMU->enablePowerOutput(XPOWERS_ALDO3);
        // MM disable GPS, it will be turned on only during a GPS cycle !!!!!!!!!!!!!!!!!
        PMU->disablePowerOutput(XPOWERS_ALDO3);

        // Set constant current charge current limit
        PMU->setChargerConstantCurr(XPOWERS_AXP2101_CHG_CUR_500MA);

        // Set charge cut-off voltage
        PMU->setChargeTargetVoltage(XPOWERS_AXP2101_CHG_VOL_4V2);

        // Disable all interrupts
        PMU->disableIRQ(XPOWERS_AXP2101_ALL_IRQ);
        // Clear all interrupt flags
        PMU->clearIrqStatus();
        // Enable the required interrupt function
        PMU->enableIRQ(
            XPOWERS_AXP2101_BAT_INSERT_IRQ    | XPOWERS_AXP2101_BAT_REMOVE_IRQ      |   //BATTERY
            XPOWERS_AXP2101_VBUS_INSERT_IRQ   | XPOWERS_AXP2101_VBUS_REMOVE_IRQ     |   //VBUS
            XPOWERS_AXP2101_PKEY_SHORT_IRQ    | XPOWERS_AXP2101_PKEY_LONG_IRQ       |   //POWER KEY
            XPOWERS_AXP2101_BAT_CHG_DONE_IRQ  | XPOWERS_AXP2101_BAT_CHG_START_IRQ       //CHARGE
            // XPOWERS_AXP2101_PKEY_NEGATIVE_IRQ | XPOWERS_AXP2101_PKEY_POSITIVE_IRQ   |   //POWER KEY
        );
    }

    PMU->enableSystemVoltageMeasure();
    PMU->enableVbusVoltageMeasure();
    PMU->enableBattVoltageMeasure();

    // Set the time of pressing the button to turn off
    PMU->setPowerKeyPressOffTime(XPOWERS_POWEROFF_4S);

   // printPMUVoltages();
    return true;
}

void PMUSavingMode()
{
    if (!PMU)return;

    //PMU->setChargingLedMode(XPOWERS_CHG_LED_OFF);
    // Disable the PMU measurement section
    PMU->disableSystemVoltageMeasure();
    PMU->disableVbusVoltageMeasure();
    PMU->disableBattVoltageMeasure();
    PMU->disableTemperatureMeasure();
    PMU->disableBattDetection();

    if (PMU->getChipModel() == XPOWERS_AXP2101) {

        // Disable all PMU interrupts
        PMU->disableIRQ(XPOWERS_AXP2101_ALL_IRQ);
        // Clear the PMU interrupt status before sleeping, otherwise the sleep current will increase
        PMU->clearIrqStatus();

        // GNSS RTC Power , Turning off GPS backup voltage and current can further reduce ~ 100 uA
        // MM leave this on, to keep GPS history ????
        // PMU->disablePowerOutput(XPOWERS_VBACKUP);

        // LoRa VDD
        PMU->disablePowerOutput(XPOWERS_ALDO2);
        // GNSS VDD
        PMU->disablePowerOutput(XPOWERS_ALDO3);

        PMU->disablePowerOutput(XPOWERS_DCDC2);
        PMU->disablePowerOutput(XPOWERS_DCDC3);
        PMU->disablePowerOutput(XPOWERS_DCDC4);
        PMU->disablePowerOutput(XPOWERS_DCDC5);
        PMU->disablePowerOutput(XPOWERS_ALDO1);
        PMU->disablePowerOutput(XPOWERS_ALDO4);
        PMU->disablePowerOutput(XPOWERS_BLDO1);
        PMU->disablePowerOutput(XPOWERS_BLDO2);
        PMU->disablePowerOutput(XPOWERS_DLDO1);
        PMU->disablePowerOutput(XPOWERS_DLDO2);
        PMU->disablePowerOutput(XPOWERS_CPULDO);
    } 
}

void printWakeupReason()
{
    Serial.print("Reset reason:");
    esp_sleep_wakeup_cause_t wakeup_reason;
    wakeup_reason = esp_sleep_get_wakeup_cause();
    switch (wakeup_reason) {
    case ESP_SLEEP_WAKEUP_UNDEFINED:
        Serial.println("Wakeup undefined");
        break;
    case ESP_SLEEP_WAKEUP_ALL :
        break;
    case ESP_SLEEP_WAKEUP_EXT0 :
        Serial.println("Wakeup caused by external signal using RTC_IO");
        break;
    case ESP_SLEEP_WAKEUP_EXT1 :
        Serial.println("Wakeup caused by external signal using RTC_CNTL");
        break;
    case ESP_SLEEP_WAKEUP_TIMER :
        Serial.println("Wakeup caused by timer");
        break;
    case ESP_SLEEP_WAKEUP_TOUCHPAD :
        Serial.println("Wakeup caused by touchpad");
        break;
    case ESP_SLEEP_WAKEUP_ULP :
        Serial.println("Wakeup caused by ULP program");
        break;
    default :
        Serial.printf("Wakeup was not caused by deep sleep: %d\n", wakeup_reason);
        break;
    }
}
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

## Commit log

2025-10-07 Added PCB design to be adapted/updated
    [HittseStress2025.kicad_pcb, HittseStress2025.kicad_sch]
2025-10-13 Updated to version 2025 for use with LilyGO T-Beam V1.2
    [HittseStress2025.kicad_pcb, HittseStress2025.kicad_sch]
2025-11-03 Corrected position of components
    [HittseStress2025.kicad_pcb]
2025-11-23 Added documentation on housing
2025-11-24 Added hittestress2025_SPS_omhulsel_TPU.stl and updated documentation
    [hittestress2025_SPS_omhulsel_TPU.stl]

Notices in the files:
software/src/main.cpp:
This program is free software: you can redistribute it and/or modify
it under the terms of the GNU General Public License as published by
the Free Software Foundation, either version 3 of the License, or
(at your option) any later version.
